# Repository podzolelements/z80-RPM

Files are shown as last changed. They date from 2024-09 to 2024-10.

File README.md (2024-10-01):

# The z80 Rapid Prototyping Module v1.1

---

image info

---

The z80 RPM is a credit-card sized single board computer designed for prototyping hardware for the z80. With 8 built-in IO device select pins and every signal on the z80 available as a breakout, new hardware can quickly be tested and iterated upon, without the hassle of connecting the hardware to an existing z80 system. I wanted to create something of a 1980's Arduino: enough hardware to get a fully functional system, while keeping the footprint as small as possible and with all the signals exposed so I could hook up anything I want to it. I also designed the board around being able to add shields or hats for standalone z80 projects.

# Hardware Features

- 3 Memory Configurations (selectable via jumpers on board):
  
  - 56kb RAM and 8kb ROM (both 16k and 8k jumpers)
  
  - 48kb RAM and 16kb ROM (16k jumper)
  
  - 32kb RAM and 32kb ROM (no jumpers)

- 8 IO 'Chip Select' pins connected to bits A5-A7

- ZIF socket for easy ROM replacement

- Automatic reset on power up with manual reset button

- 90mm by 57mm footprint

- Entirety of the z80's pins are accessible and labeled via breakout

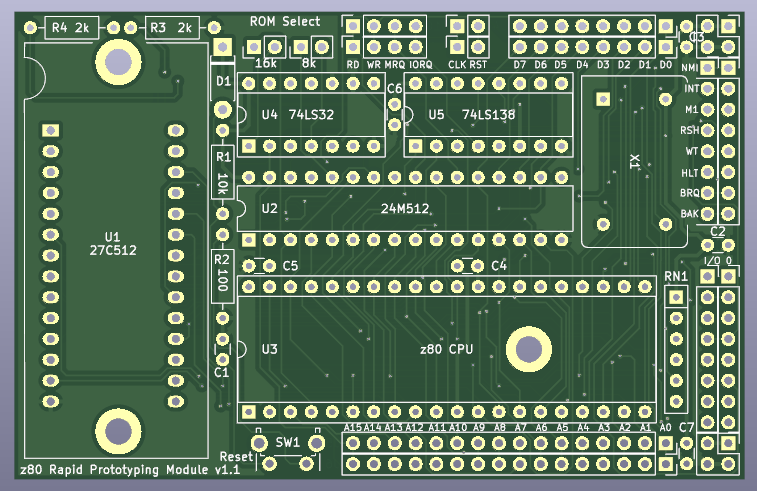
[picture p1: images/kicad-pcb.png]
image info


# Memory & IO Address Map

56k/8k memory configuration:

- ROM: 0x0000 - 0x1fff

- RAM: 0x2000 - 0xffff

48k/16k memory configuration:

- ROM: 0x0000 - 0x3fff

- RAM: 0x4000 - 0xffff

32k/32k memory configuration:

- ROM: 0x0000 - 0x7fff

- RAM: 0x8000 - 0xffff

IO map:

- 0b000xxxxx: IO device select 0

- 0b001xxxxx: IO device select 1

- 0b010xxxxx: IO device select 2

- 0b011xxxxx: IO device select 3

- 0b100xxxxx: IO device select 4

- 0b101xxxxx: IO device select 5

- 0b110xxxxx: IO device select 6

- 0b111xxxxx: IO device select 7

# Pinout

*Note this is the board layout from v1.0, however the pin locations have not changed*

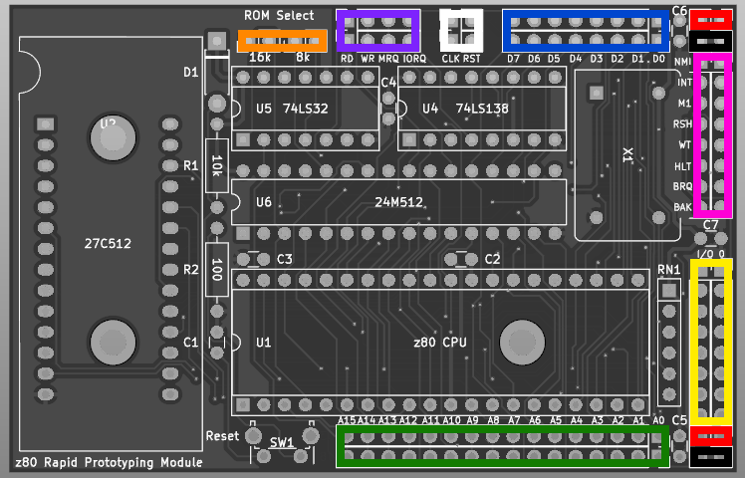
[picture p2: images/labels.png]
image info


Going clockwise starting from the top:

- Orange - Memory configuration jumpers

- Purple - Data signals

- White - Clock and reset

- Blue - Data bus

- Pink - z80 signals

- Yellow - IO device selects

- Green - Address bus

Some notes: Red and Black are +5v and GND respectively. Due to limited space on the board, the IO device select lines are not labeled. IO device 0 is at the top, device 1 is below device 0, etc, and device 7 is on the bottom, right above the lower +5v connection.

# Schematic

A PDF version is also available in the schematics folder.

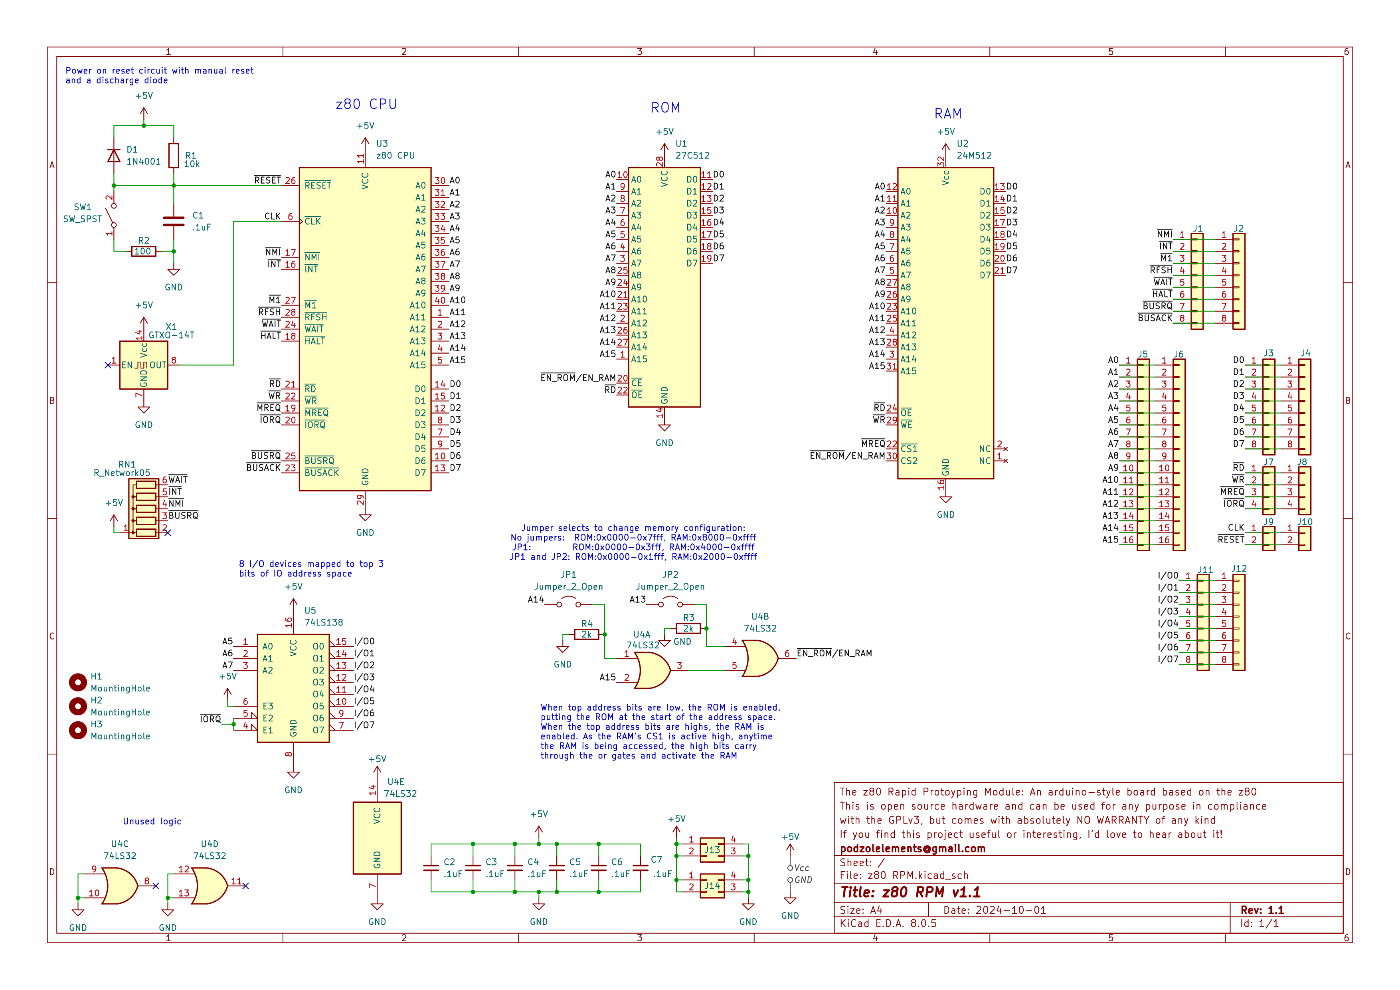
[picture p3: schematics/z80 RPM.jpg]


# Bill of Materials

If you'd like to recreate this project, here are all the parts on the PCB. Other parts likely can be substituted in, but be sure to check with the datasheets to ensure they are actually compatible. As a side note, I socket all of my IC's, which allows the removal of the IC's from the board, but they are not absolutely necessary.

| Part Reference | Value | Purpose |
| --- | --- | --- |
| C2,C3,C4,C5,C6,C7 | .1uF | Decoupling capacitors |
| C1 | .1uF | Automatic reset circuit |
| D1 | 1N40001 | Automatic reset circuit |
| R1 | 10k | Automatic reset circuit |
| R2 | 100 | Automatic reset circuit |
| R3,R4 | 2k | Memory configuration pulldowns |
| RN1 | 10k | z80 input pin pullups |
| SW1 | Tactile switch | Manual reset button |
| U1 | 27C512 (ZIF 28 socket) | 64k EEPROM |
| U2 | 24M512 | 64k SRAM |
| U3 | z80 CPU | CPU |
| U4 | 74LS32 | Memory configuration logic |
| U5 | 74LS138 | IO device port decoder |
| X1 | DIP 14 oscillator can  | CPU clock |

# Images

*Note all images are from v1.0*

Here's the RPM in action (I've got it hooked up to an SAA1099 here):

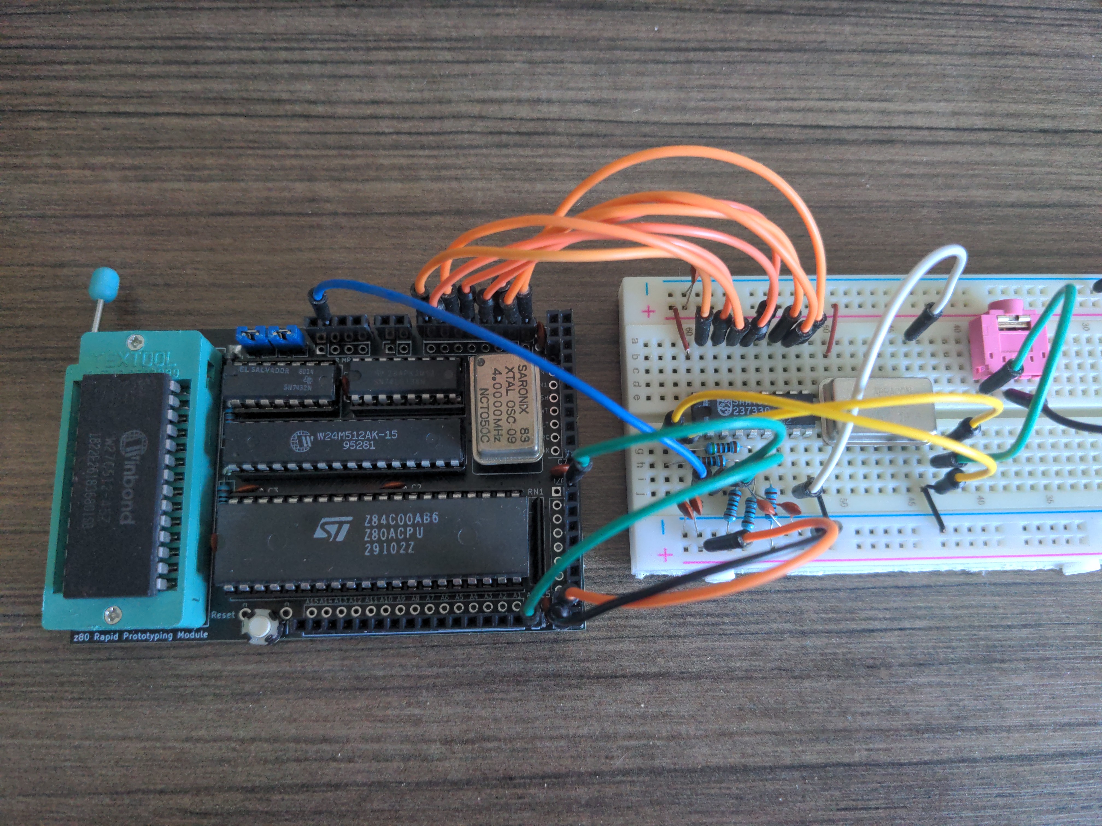
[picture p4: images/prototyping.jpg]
image info


Build progress:

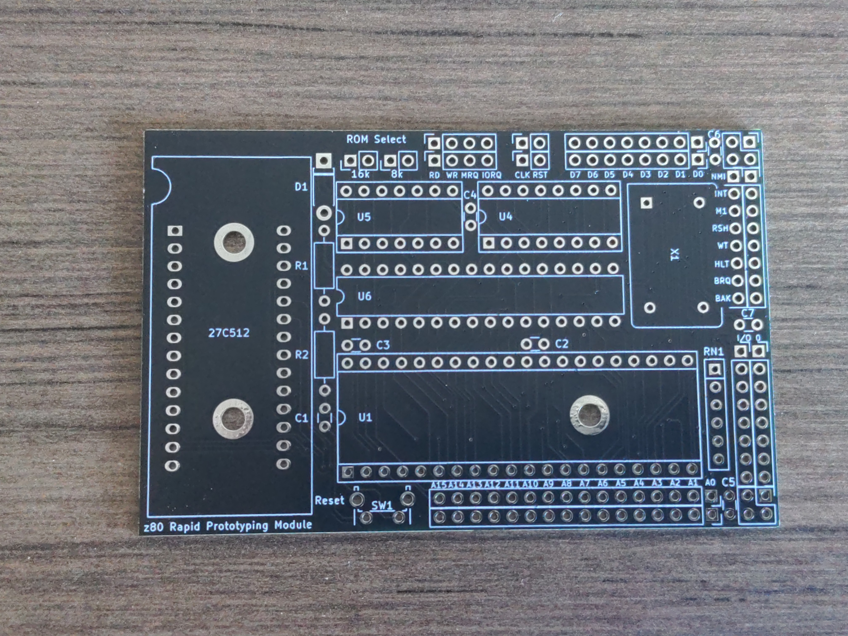
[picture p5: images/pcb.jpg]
image info


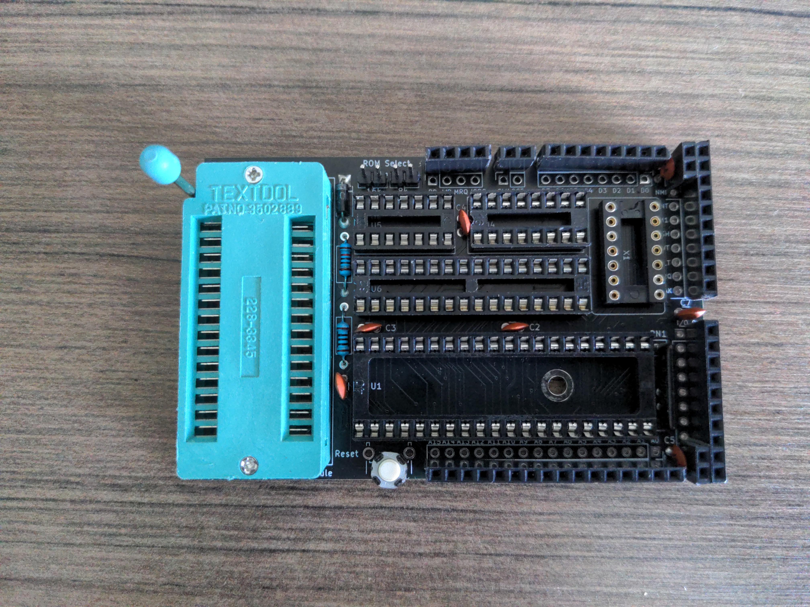
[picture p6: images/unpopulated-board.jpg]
image info


This project is open source and can be used for any purpose in compliance with the GPLv3, but comes with absolutely NO WARRANTY of any kind.

Thanks for checking out my project! If you find this project useful or interesting, I'd love to hear about it!

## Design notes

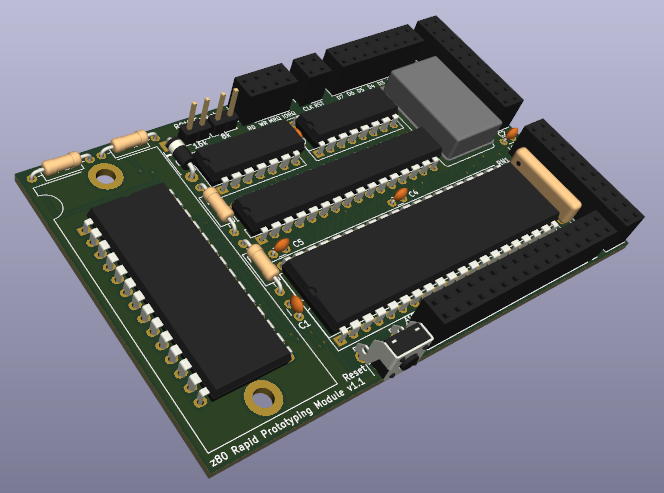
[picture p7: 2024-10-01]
images/kicad-render-angled.png

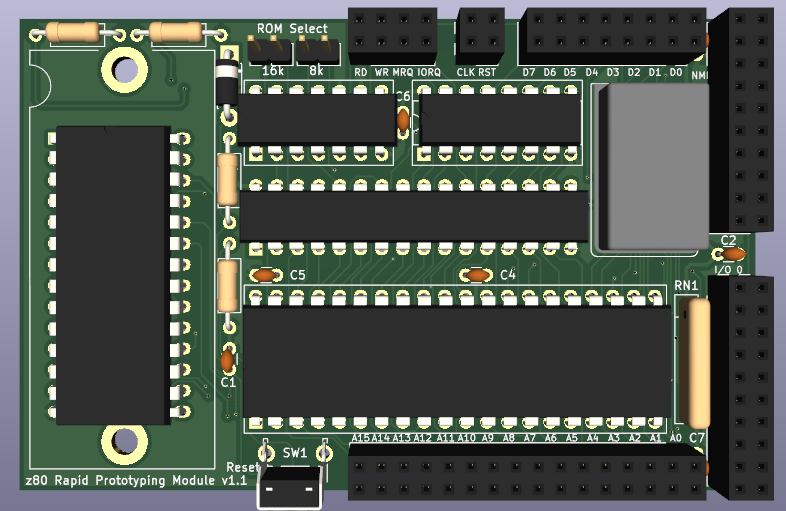
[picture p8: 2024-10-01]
images/kicad-render.png

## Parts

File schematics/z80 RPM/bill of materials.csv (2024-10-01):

Reference | Value | Datasheet | Footprint | Qty | DNP
C1,C2,C3,C4,C5,C6,C7 | .1uF | ~ | Capacitor_THT:C_Disc_D3.0mm_W1.6mm_P2.50mm | 7
D1 | 1N4001 | ~ | Diode_THT:D_DO-41_SOD81_P7.62mm_Horizontal | 1
J1,J2,J3,J4,J11,J12 | Conn_01x08 | ~ | Connector_PinSocket_2.54mm:PinSocket_1x08_P2.54mm_Vertical | 6
J5,J6 | Conn_01x16 | ~ | Connector_PinSocket_2.54mm:PinSocket_1x16_P2.54mm_Vertical | 2
J7,J8 | Conn_01x04 | ~ | Connector_PinSocket_2.54mm:PinSocket_1x04_P2.54mm_Vertical | 2
J9,J10 | Conn_01x02 | ~ | Connector_PinSocket_2.54mm:PinSocket_1x02_P2.54mm_Vertical | 2
J13,J14 | Conn_02x02_Counter_Clockwise | ~ | Connector_PinSocket_2.54mm:PinSocket_2x02_P2.54mm_Vertical | 2
JP1,JP2 | Jumper_2_Open | ~ | Connector_PinHeader_2.54mm:PinHeader_1x02_P2.54mm_Vertical | 2
R1 | 10k | ~ | Resistor_THT:R_Axial_DIN0207_L6.3mm_D2.5mm_P10.16mm_Horizontal | 1
R2 | 100 | ~ | Resistor_THT:R_Axial_DIN0207_L6.3mm_D2.5mm_P10.16mm_Horizontal | 1
R3,R4 | 2k | ~ | Resistor_THT:R_Axial_DIN0207_L6.3mm_D2.5mm_P10.16mm_Horizontal | 2
RN1 | R_Network05 | http://www.vishay.com/docs/31509/csc.pdf | Resistor_THT:R_Array_SIP6 | 1
SW1 | SW_SPST | ~ | Button_Switch_THT:SW_Tactile_SPST_Angled_PTS645Vx31-2LFS | 1
U1 | 27C512 | http://ww1.microchip.com/downloads/en/DeviceDoc/doc0015.pdf | Socket:DIP_Socket-28_W11.9_W12.7_W15.24_W17.78_W18.5_3M_228-1277-00-0602J | 1
U2 | 24M512 |  | Package_DIP:DIP-32_W7.62mm | 1
U3 | z80 CPU | www.zilog.com/manage_directlink.php?filepath=docs/z80/um0080 | Package_DIP:DIP-40_W15.24mm_Socket | 1
U4 | 74LS32 | http://www.ti.com/lit/gpn/sn74LS32 | Package_DIP:DIP-14_W7.62mm_Socket | 1
U5 | 74LS138 | http://www.ti.com/lit/gpn/sn74LS138 | Package_DIP:DIP-16_W7.62mm_Socket | 1
X1 | GTXO-14T | http://www.golledge.com/pdf/products/tcxos/gtxo14.pdf | Oscillator:Oscillator_DIP-14 | 1

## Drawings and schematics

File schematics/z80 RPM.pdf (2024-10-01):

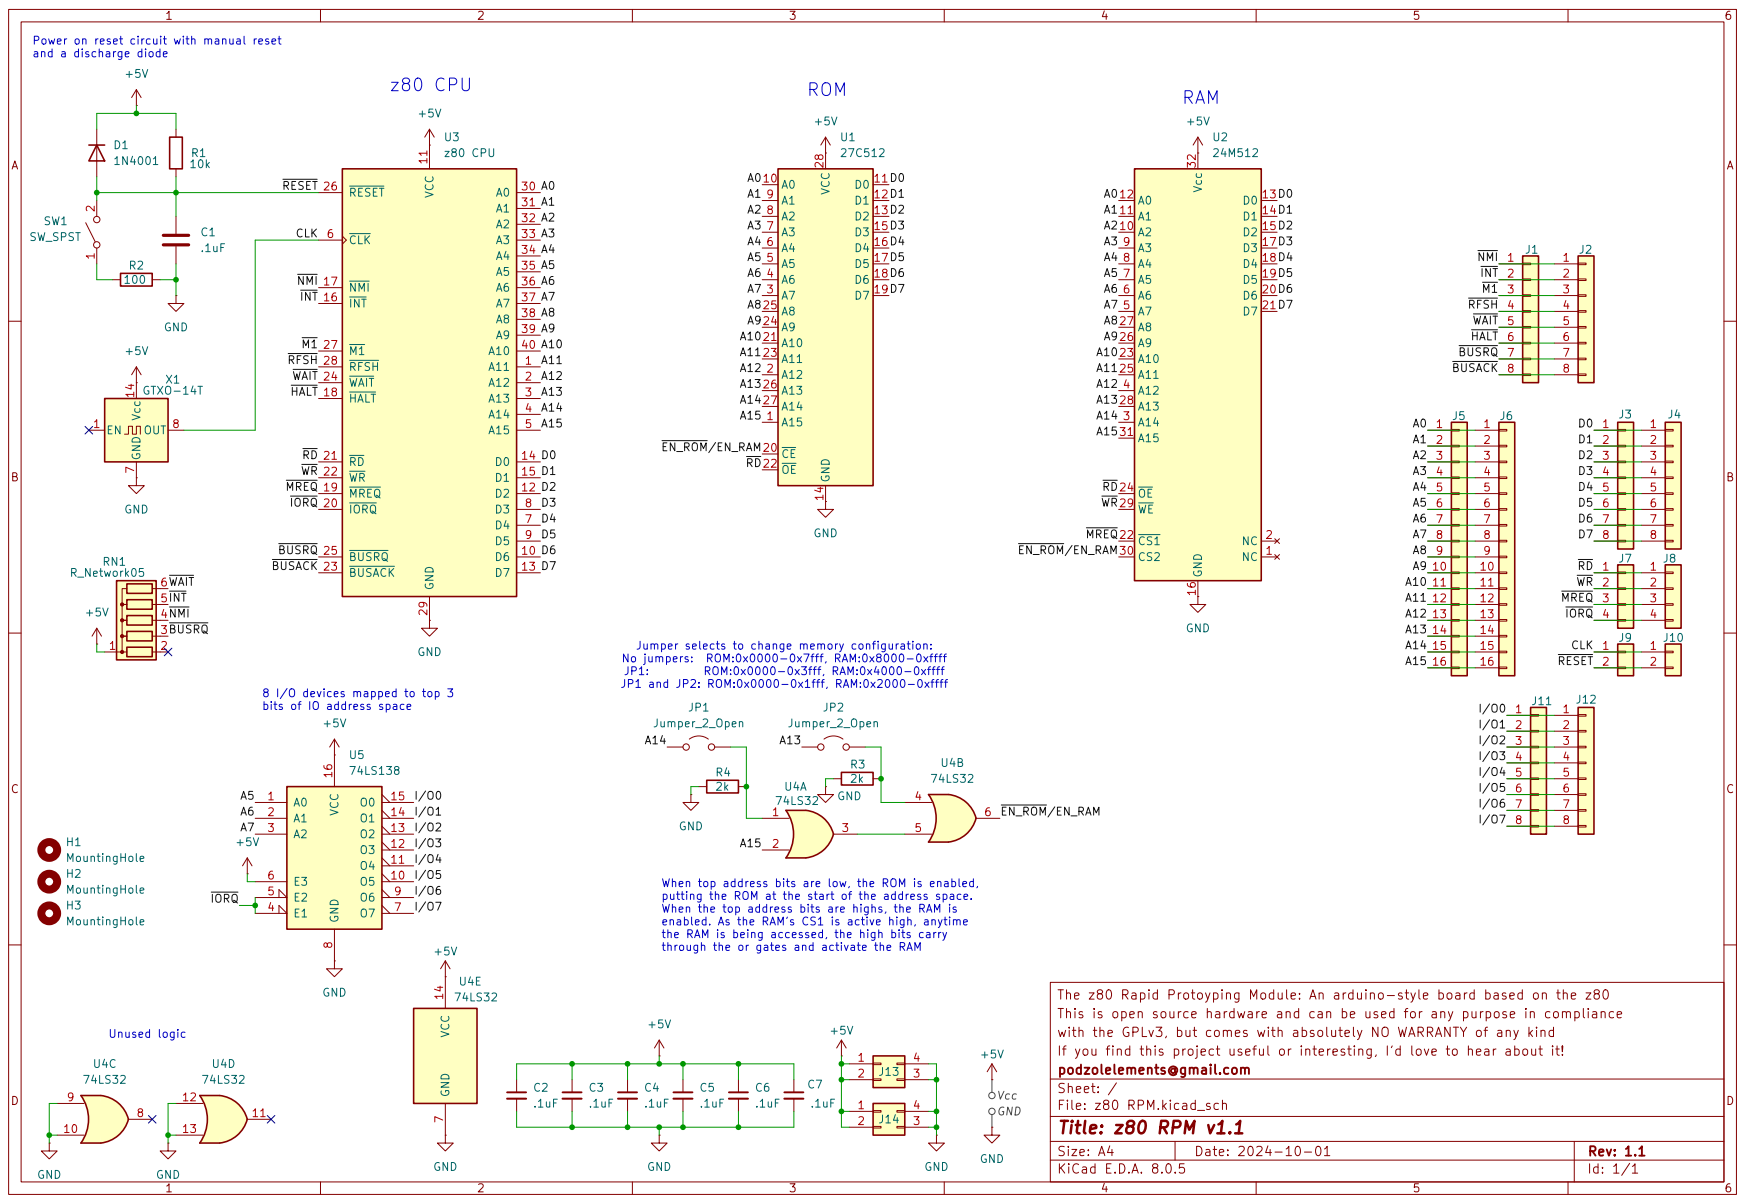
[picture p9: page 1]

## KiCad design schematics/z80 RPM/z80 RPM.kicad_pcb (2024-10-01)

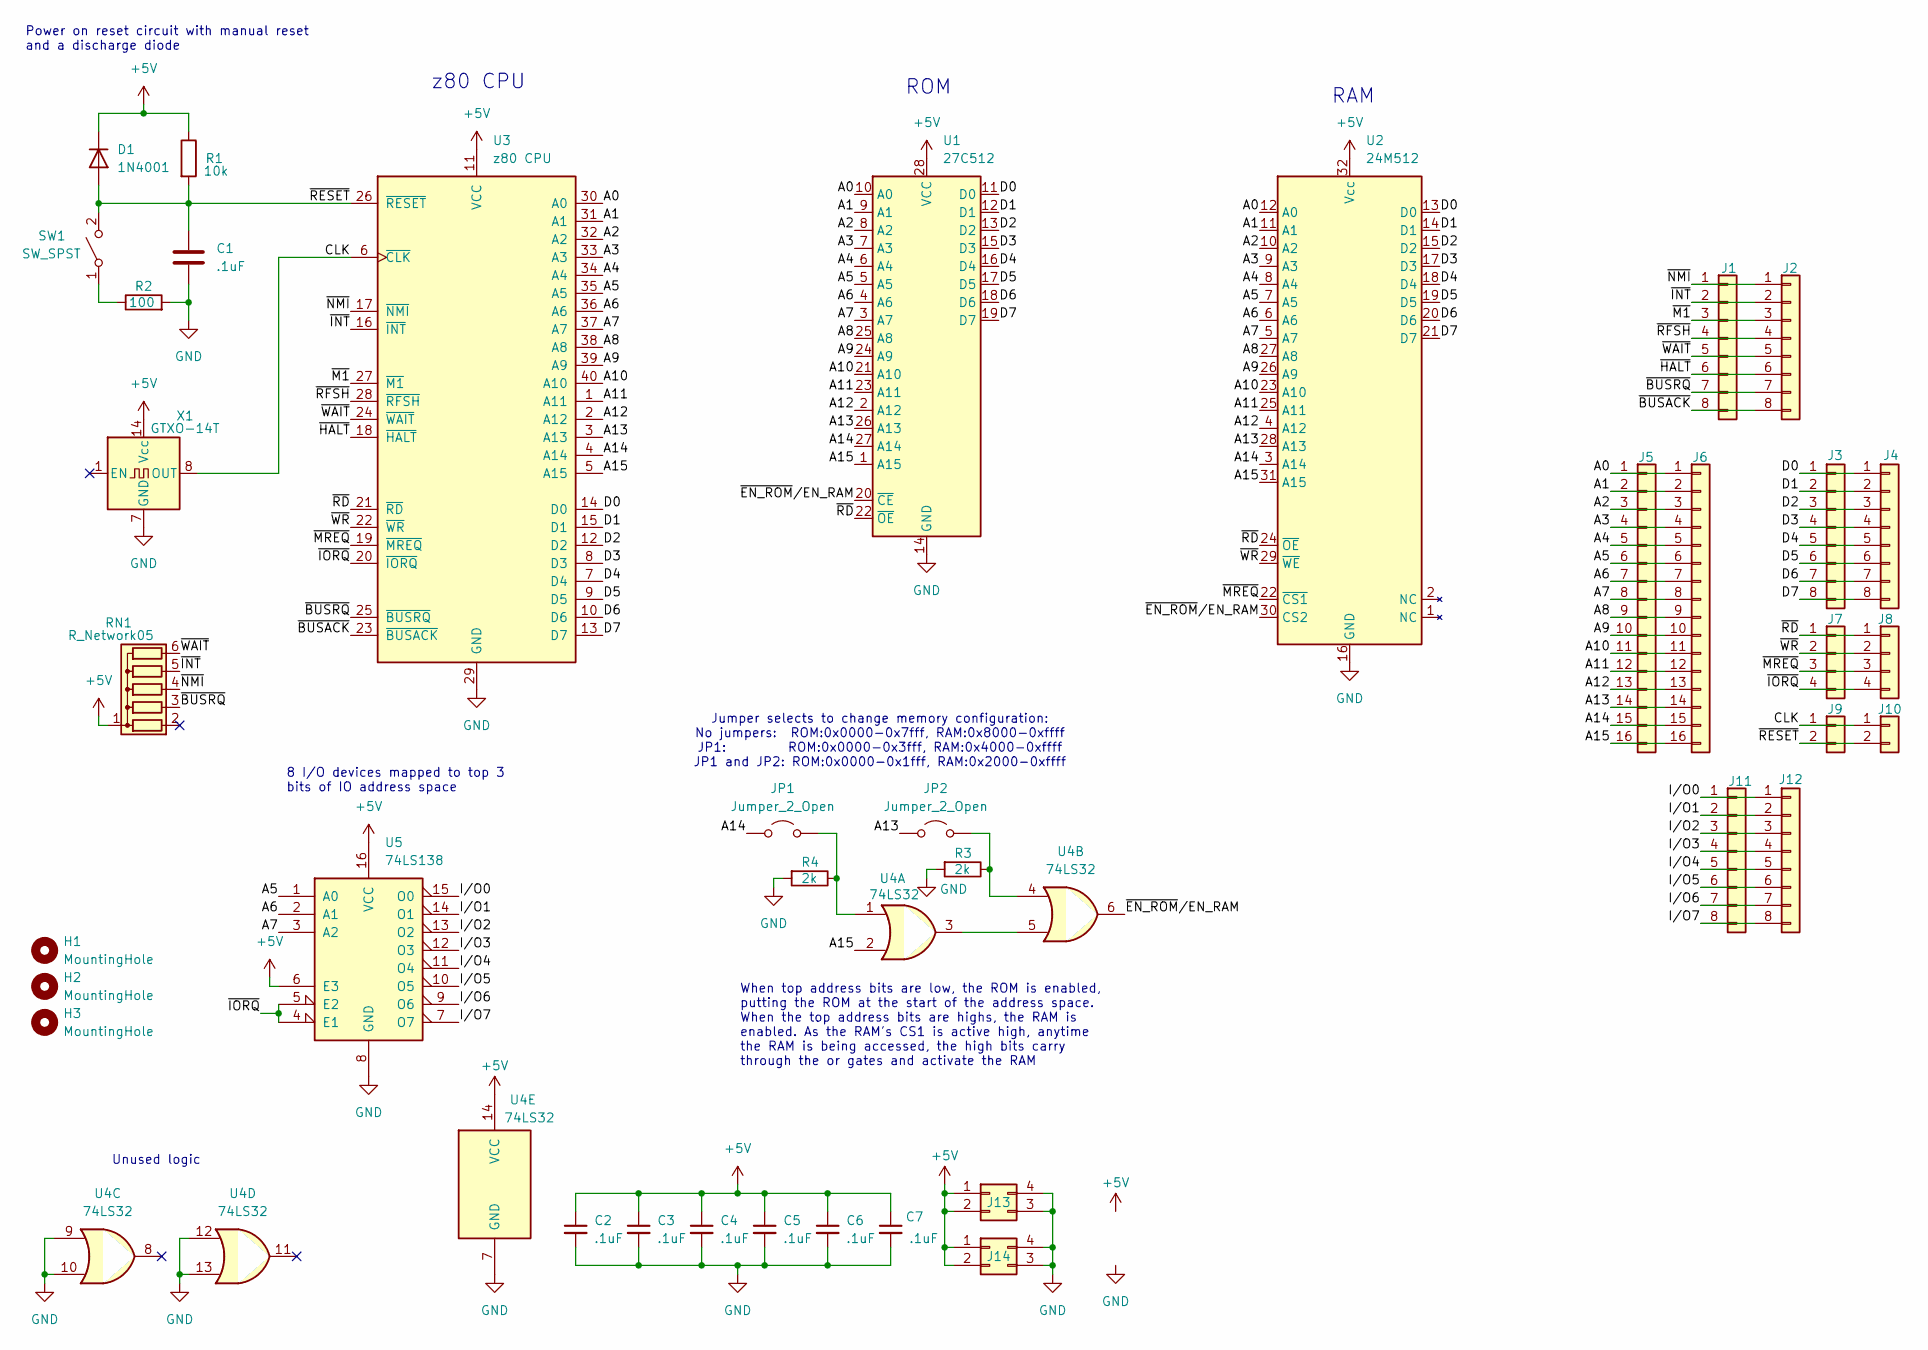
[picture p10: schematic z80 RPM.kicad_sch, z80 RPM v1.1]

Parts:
C1, C2, C3, C4, C5, C6, C7: .1uF; C_Disc_D3.0mm_W1.6mm_P2.50mm
D1: 1N4001; D_DO-41_SOD81_P7.62mm_Horizontal
H1, H2, H3: MountingHole; MountingHole_3.2mm_M3_DIN965_Pad_TopBottom
J1, J2, J3, J4, J11, J12: Conn_01x08; PinSocket_1x08_P2.54mm_Vertical
J5, J6: Conn_01x16; PinSocket_1x16_P2.54mm_Vertical
J7, J8: Conn_01x04; PinSocket_1x04_P2.54mm_Vertical
J9, J10: Conn_01x02; PinSocket_1x02_P2.54mm_Vertical
J13, J14: Conn_02x02_Counter_Clockwise; PinSocket_2x02_P2.54mm_Vertical
JP1, JP2: Jumper_2_Open; PinHeader_1x02_P2.54mm_Vertical
R1: 10k; R_Axial_DIN0207_L6.3mm_D2.5mm_P10.16mm_Horizontal
R2: 100; R_Axial_DIN0207_L6.3mm_D2.5mm_P10.16mm_Horizontal
R3, R4: 2k; R_Axial_DIN0207_L6.3mm_D2.5mm_P10.16mm_Horizontal
RN1: R_Network05; R_Array_SIP6
SW1: SW_SPST; SW_Tactile_SPST_Angled_PTS645Vx31-2LFS
U1: 27C512; DIP_Socket-28_W11.9_W12.7_W15.24_W17.78_W18.5_3M_228-1277-0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
U2: 24M512; DIP-32_W7.62mm
U3: z80 CPU; DIP-40_W15.24mm_Socket
U4: 74LS32; DIP-14_W7.62mm_Socket
U5: 74LS138; DIP-16_W7.62mm_Socket
X1: GTXO-14T; Oscillator_DIP-14

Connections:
+5V: C2.1, C3.1, C4.1, C5.1, C6.1, C7.1, D1.1 (K), J13.1, J13.2, J14.1, J14.2, R1.1, RN1.1 (common), U1.28 (VCC), U2.32 (Vcc), U3.11 (VCC), U4.14 (VCC), U5.6 (E3), U5.16 (VCC), X1.14 (Vcc)
/A0: J5.1, J6.1, U1.10 (A0), U2.12 (A0), U3.30 (A0)
/A1: J5.2, J6.2, U1.9 (A1), U2.11 (A1), U3.31 (A1)
/A2: J5.3, J6.3, U1.8 (A2), U2.10 (A2), U3.32 (A2)
/A3: J5.4, J6.4, U1.7 (A3), U2.9 (A3), U3.33 (A3)
/A4: J5.5, J6.5, U1.6 (A4), U2.8 (A4), U3.34 (A4)
/A5: J5.6, J6.6, U1.5 (A5), U2.7 (A5), U3.35 (A5), U5.1 (A0)
/A6: J5.7, J6.7, U1.4 (A6), U2.6 (A6), U3.36 (A6), U5.2 (A1)
/A7: J5.8, J6.8, U1.3 (A7), U2.5 (A7), U3.37 (A7), U5.3 (A2)
/A8: J5.9, J6.9, U1.25 (A8), U2.27 (A8), U3.38 (A8)
/A9: J5.10, J6.10, U1.24 (A9), U2.26 (A9), U3.39 (A9)
/A10: J5.11, J6.11, U1.21 (A10), U2.23 (A10), U3.40 (A10)
/A11: J5.12, J6.12, U1.23 (A11), U2.25 (A11), U3.1 (A11)
/A12: J5.13, J6.13, U1.2 (A12), U2.4 (A12), U3.2 (A12)
/A13: J5.14, J6.14, JP2.1 (A), U1.26 (A13), U2.28 (A13), U3.3 (A13)
/A14: J5.15, J6.15, JP1.1 (A), U1.27 (A14), U2.3 (A14), U3.4 (A14)
/A15: J5.16, J6.16, U1.1 (A15), U2.31 (A15), U3.5 (A15), U4.2
/CLK: J9.1, J10.1, U3.6 (~CLK), X1.8 (OUT)
/D0: J3.1, J4.1, U1.11 (D0), U2.13 (D0), U3.14 (D0)
/D1: J3.2, J4.2, U1.12 (D1), U2.14 (D1), U3.15 (D1)
/D2: J3.3, J4.3, U1.13 (D2), U2.15 (D2), U3.12 (D2)
/D3: J3.4, J4.4, U1.15 (D3), U2.17 (D3), U3.8 (D3)
/D4: J3.5, J4.5, U1.16 (D4), U2.18 (D4), U3.7 (D4)
/D5: J3.6, J4.6, U1.17 (D5), U2.19 (D5), U3.9 (D5)
/D6: J3.7, J4.7, U1.18 (D6), U2.20 (D6), U3.10 (D6)
/D7: J3.8, J4.8, U1.19 (D7), U2.21 (D7), U3.13 (D7)
/I/O0: J11.1, J12.1, U5.15 (O0)
/I/O1: J11.2, J12.2, U5.14 (O1)
/I/O2: J11.3, J12.3, U5.13 (O2)
/I/O3: J11.4, J12.4, U5.12 (O3)
/I/O4: J11.5, J12.5, U5.11 (O4)
/I/O5: J11.6, J12.6, U5.10 (O5)
/I/O6: J11.7, J12.7, U5.9 (O6)
/I/O7: J11.8, J12.8, U5.7 (O7)
/~BUSACK: J1.8, J2.8, U3.23 (~BUSACK)
/~BUSRQ: J1.7, J2.7, RN1.3 (R2), U3.25 (~BUSRQ)
/~EN_ROM/EN_RAM: U1.20 (~CE), U2.30 (CS2), U4.6
/~HALT: J1.6, J2.6, U3.18 (~HALT)
/~INT: J1.2, J2.2, RN1.5 (R4), U3.16 (~INT)
/~IORQ: J7.4, J8.4, U3.20 (~IORQ), U5.4 (E1), U5.5 (E2)
/~M1: J1.3, J2.3, U3.27 (~M1)
/~MREQ: J7.3, J8.3, U2.22 (~CS1), U3.19 (~MREQ)
/~NMI: J1.1, J2.1, RN1.4 (R3), U3.17 (~NMI)
/~RD: J7.1, J8.1, U1.22 (~OE), U2.24 (~OE), U3.21 (~RD)
/~RESET: C1.1, D1.2 (A), J9.2, J10.2, R1.2, SW1.2 (B), U3.26 (~RESET)
/~RFSH: J1.4, J2.4, U3.28 (~RFSH)
/~WAIT: J1.5, J2.5, RN1.6 (R5), U3.24 (~WAIT)
/~WR: J7.2, J8.2, U2.29 (~WE), U3.22 (~WR)
GND: C1.2, C2.2, C3.2, C4.2, C5.2, C6.2, C7.2, J13.3, J13.4, J14.3, J14.4, R2.2, R3.2, R4.2, U1.14 (GND), U2.16 (GND), U3.29 (GND), U4.7 (GND), U4.9, U4.10, U4.12, U4.13, U5.8 (GND), X1.7 (GND)
unnamed: JP1.2 (B), R4.1, U4.1
unnamed: JP2.2 (B), R3.1, U4.4
unnamed: R2.1, SW1.1 (A)
unnamed: U4.3, U4.5

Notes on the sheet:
8 I/O devices mapped to top 3 bits of IO address space
z80 CPU
Unused logic
Jumper selects to change memory configuration: No jumpers: ROM:0x0000-0x7fff, RAM:0x8000-0xffff JP1: ROM:0x0000-0x3fff, RAM:0x4000-0xffff JP1 and JP2: ROM:0x0000-0x1fff, RAM:0x2000-0xffff
When top address bits are low, the ROM is enabled, putting the ROM at the start of the address space. When the top address bits are highs, the RAM is enabled. As the RAM's CS1 is active high, anytime the RAM is being accessed, the high bits carry through the or gates and activate the RAM
RAM
Power on reset circuit with manual reset and a discharge diode
ROM

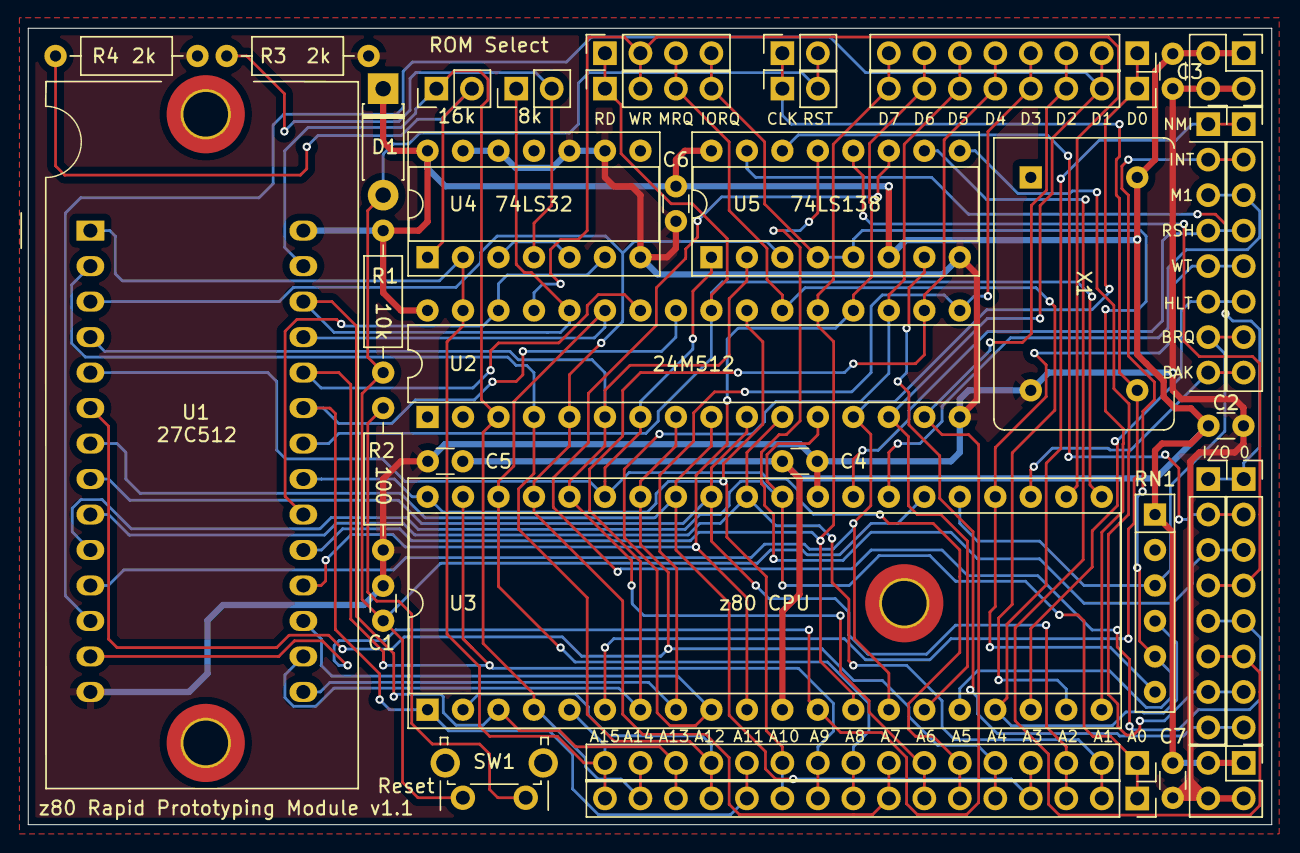
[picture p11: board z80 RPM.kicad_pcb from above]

Board: 2 copper layers, 89.0 x 57.0 mm, 39 parts (0 on the bottom side), 53 nets.

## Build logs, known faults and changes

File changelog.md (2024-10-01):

# v1.1

10/01/2024

Minor hardware modifications and PCB cleanup.

- Memory select jumpers now have pulldown resistors
  
  - Without the pulldowns, the 74LS32's inputs were left floating when the memory configuration jumpers were not connected. This caused only the 56k/8k memory mode to work properly
- Mounting holes have been relocated to more accessable positions

# v1.0

09/24/2024

Inital design release.

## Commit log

2024-09-25 added schematic images and cleaned up schematic
    [z80 RPM (another copy).kicad_pcb, z80 RPM.kicad_sch]
2024-09-26 added README
    [bill of materials.csv, z80 RPM.kicad_pcb, z80 RPM.kicad_sch]
2024-10-01 design updated to v1.1
    [bill of materials.csv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]
